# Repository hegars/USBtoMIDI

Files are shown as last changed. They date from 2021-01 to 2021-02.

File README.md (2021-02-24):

# USBtoMIDI

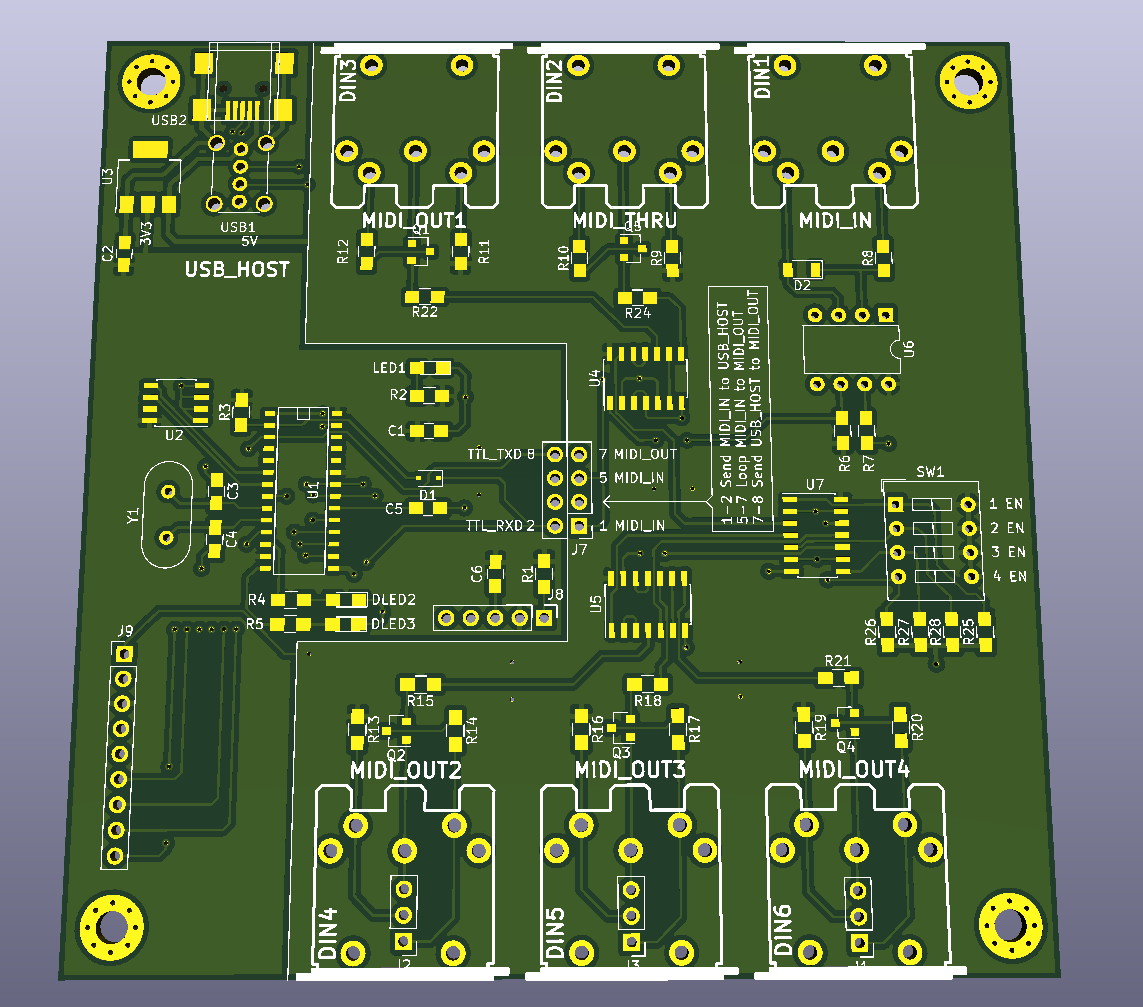
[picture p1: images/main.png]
usbtomidi


KiCAD design for Isolated 1 IN, 1 THRU and 4 OUT (with disable) MIDI distributor with USB Host Midi controller based on Microchip 24FJ64GB002 microcontroller with code from (https://www.hobbytronics.co.uk/audio-midi/usb-host-midi) on a 100mm x 100mm board for low cost production

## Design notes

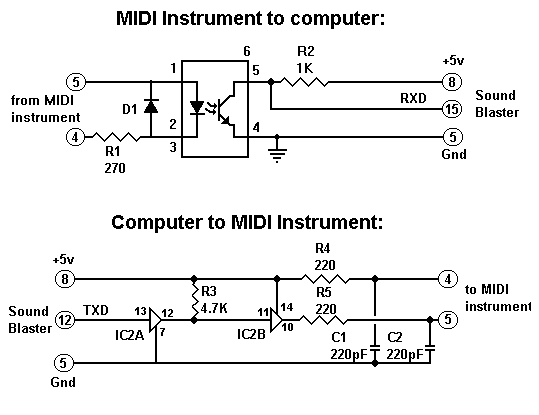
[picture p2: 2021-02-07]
images/sbmidi1.gif

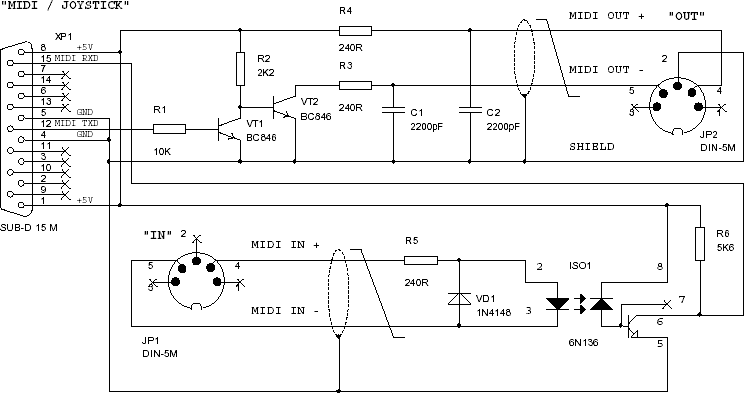
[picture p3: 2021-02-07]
images/image_pc2midicable.png

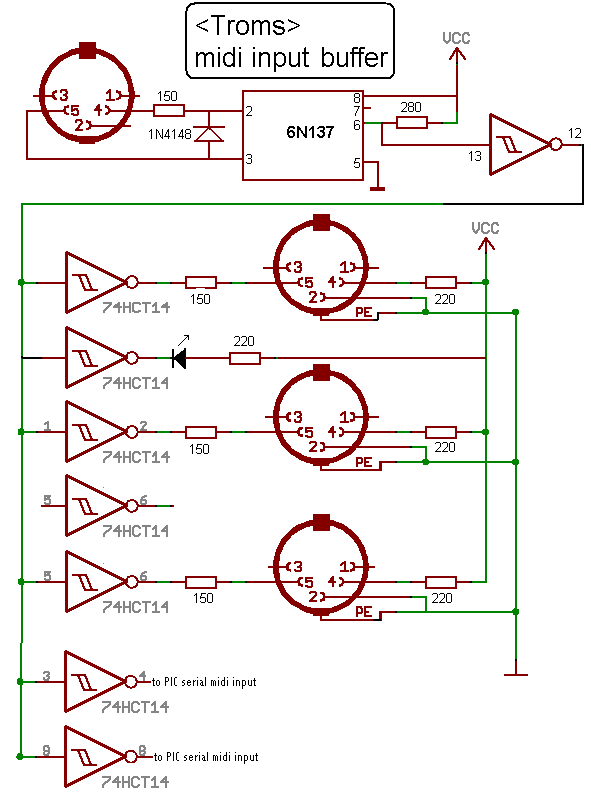
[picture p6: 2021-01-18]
images/SCH_Midibuffer.gif

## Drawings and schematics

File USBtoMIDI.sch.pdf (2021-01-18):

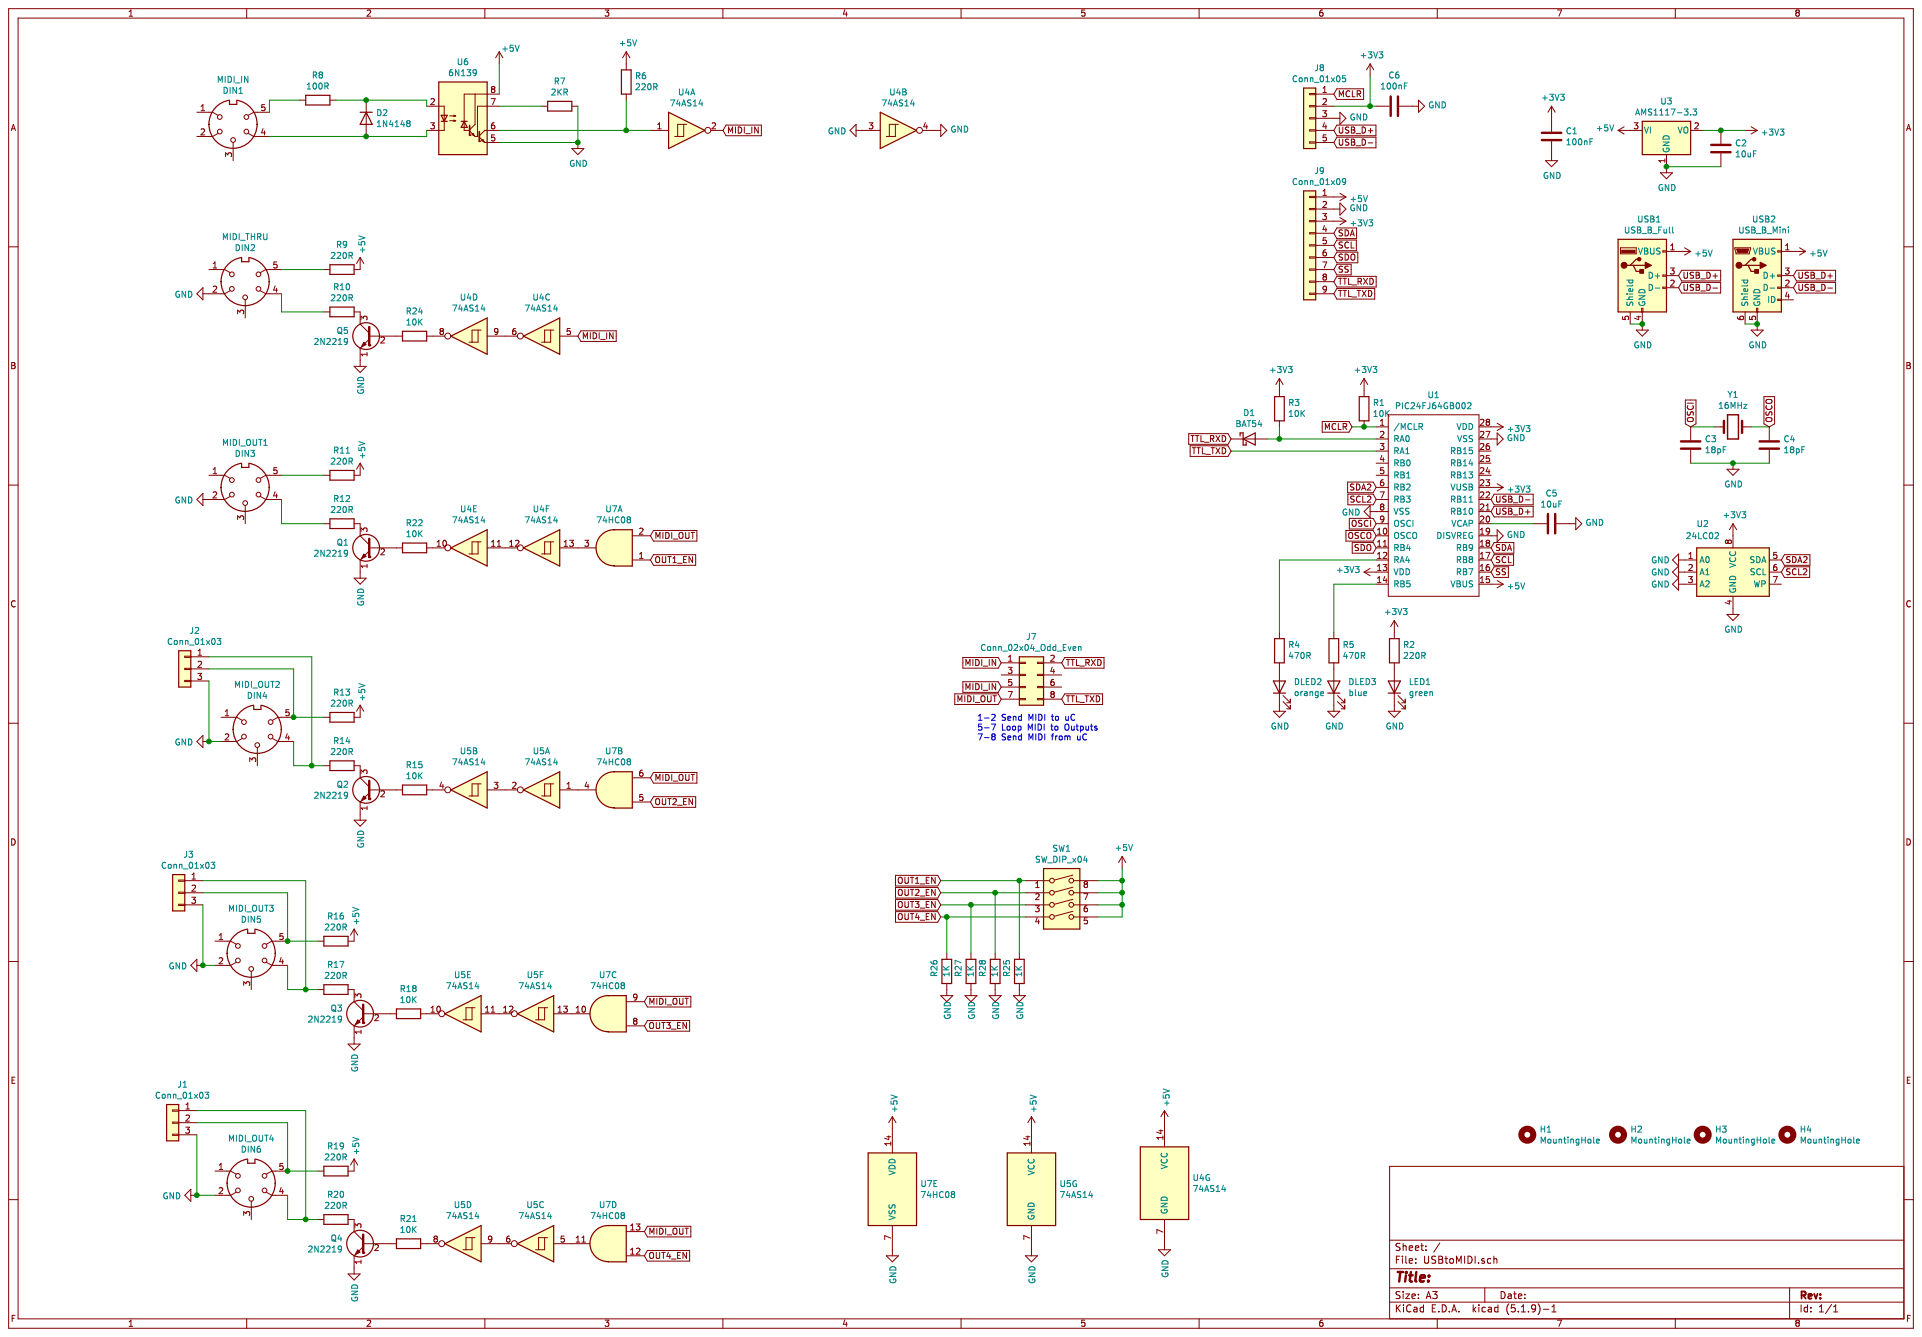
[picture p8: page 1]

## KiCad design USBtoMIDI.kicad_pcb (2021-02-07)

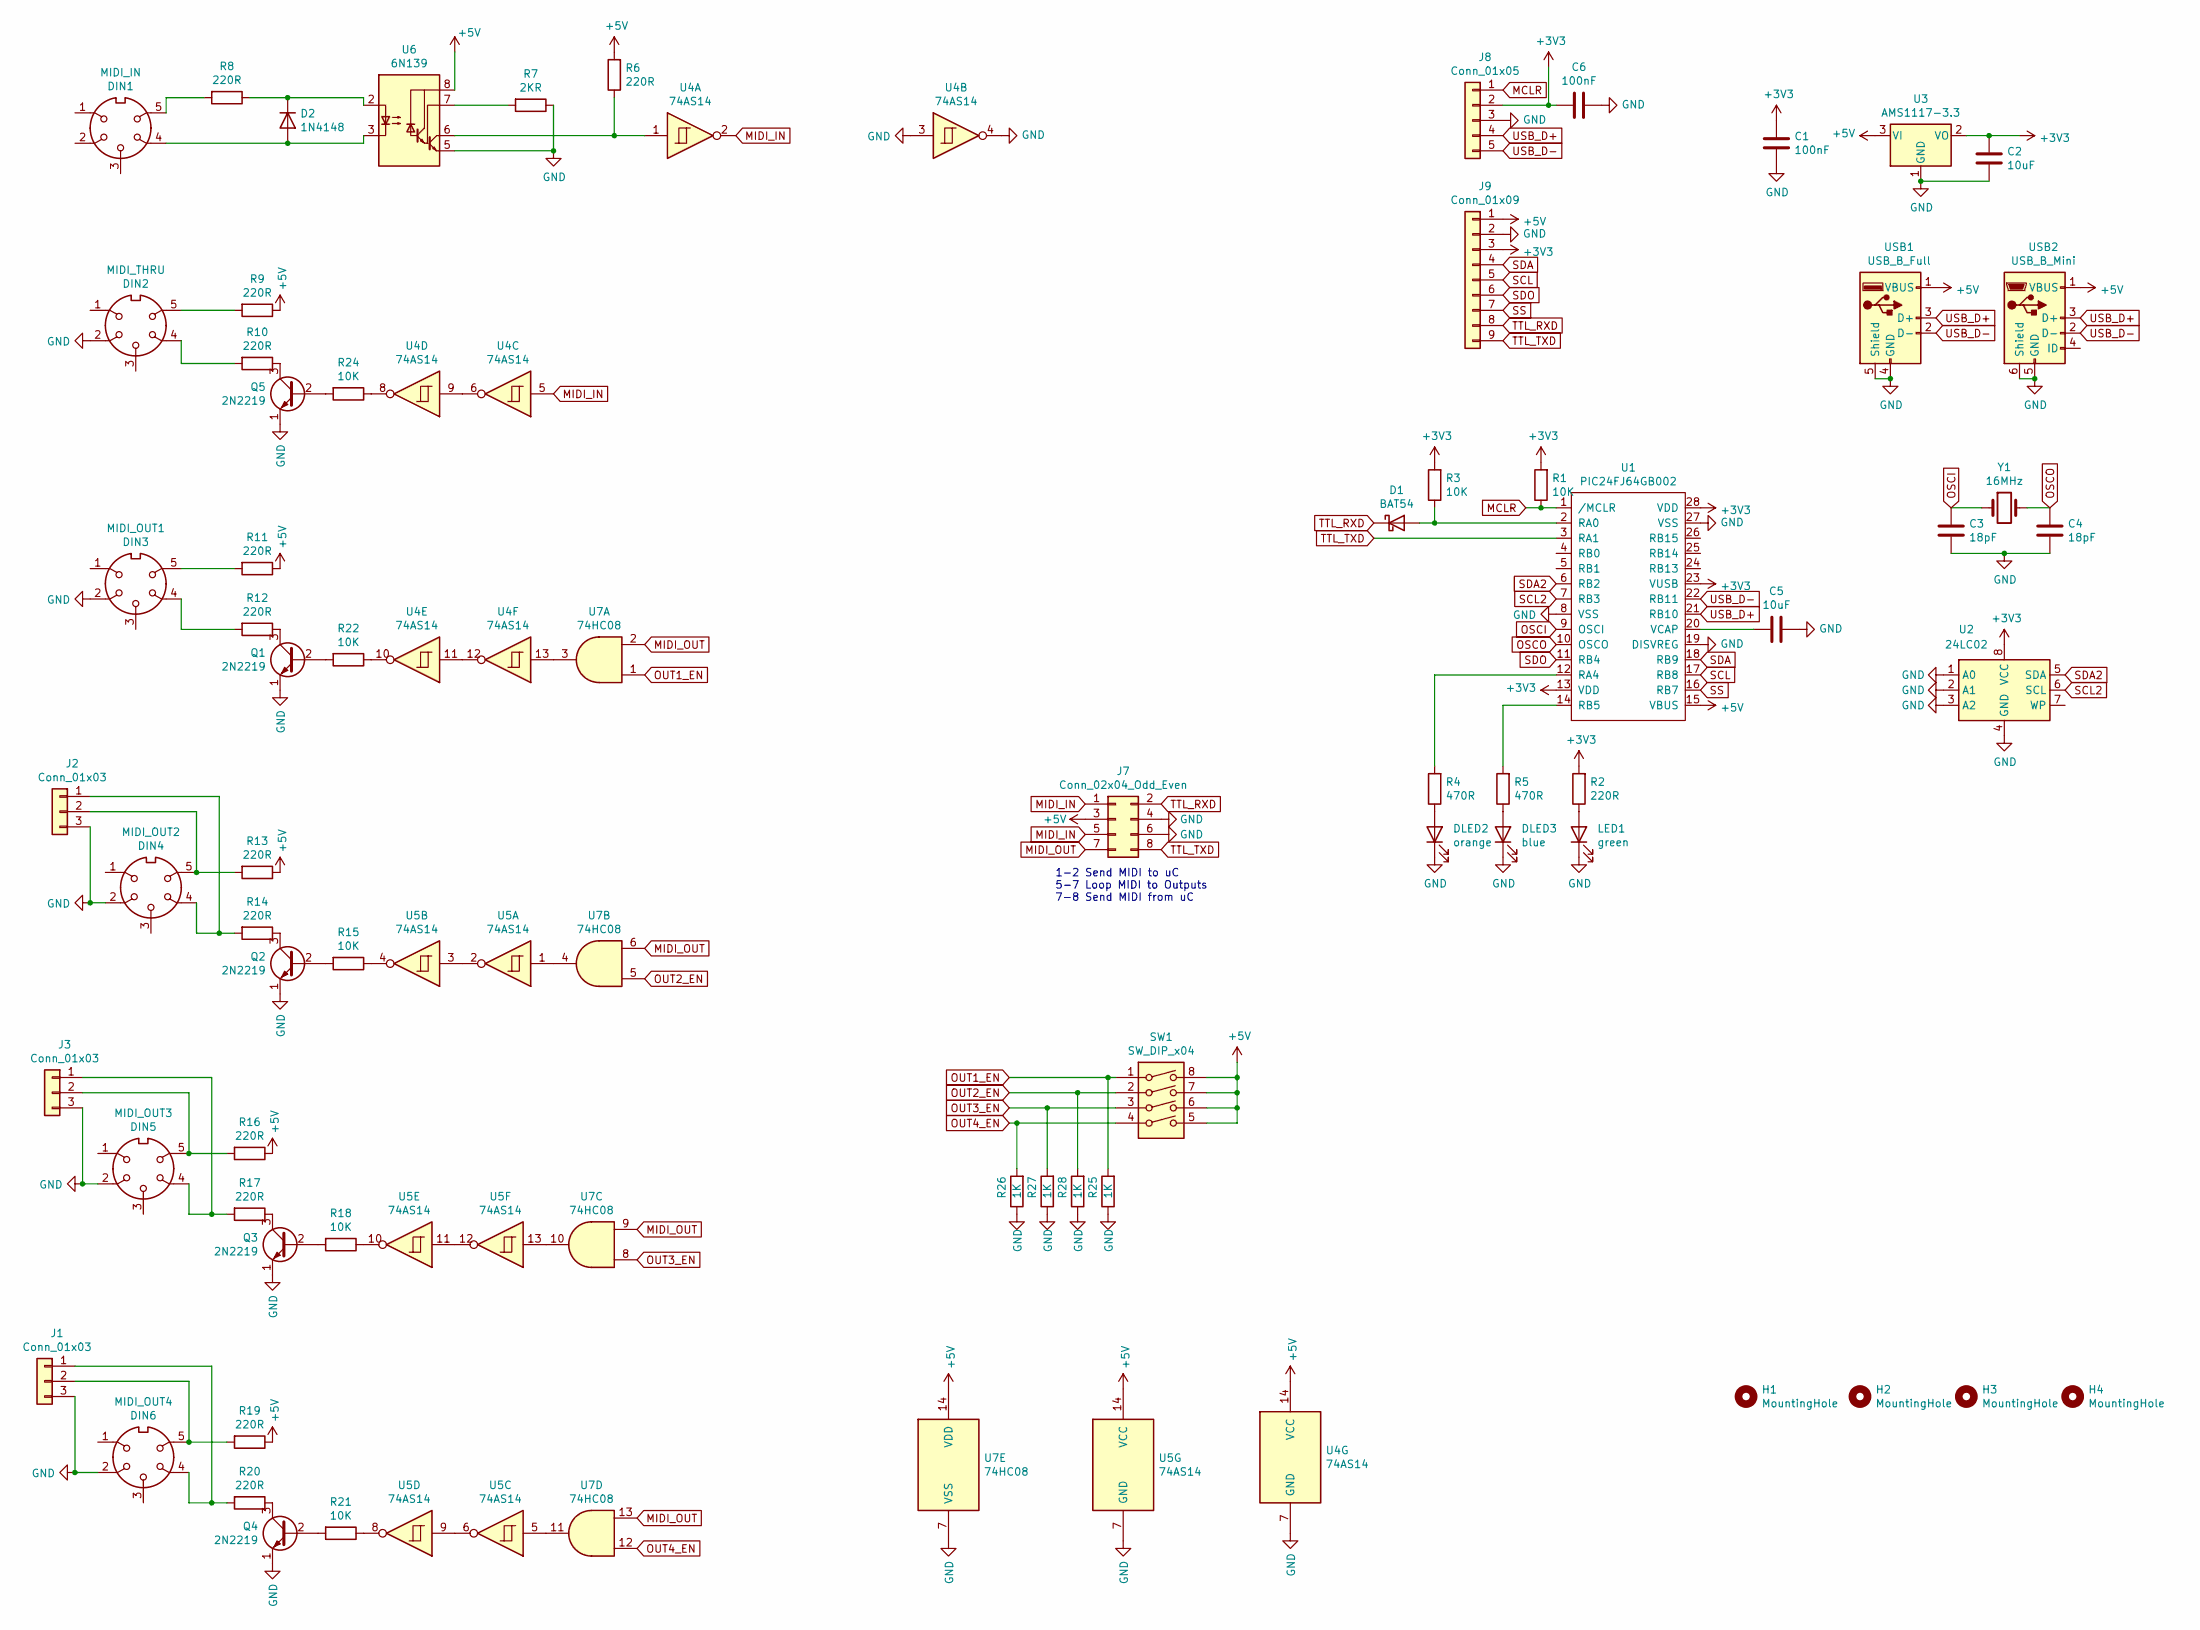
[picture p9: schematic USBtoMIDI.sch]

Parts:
C1, C6: 100nF; C_0805_HandSoldering
C2, C5: 10uF; C_0805_HandSoldering
C3, C4: 18pF; C_0805_HandSoldering
D1: BAT54; D_SOD-323
D2: 1N4148; D_1206
DIN1: MIDI_IN; din-5
DIN2: MIDI_THRU; din-5
DIN3: MIDI_OUT1; din-5
DIN4: MIDI_OUT2; din-5
DIN5: MIDI_OUT3; din-5
DIN6: MIDI_OUT4; din-5
DLED2: orange; LED_0805_HandSoldering
DLED3: blue; LED_0805_HandSoldering
H1, H2, H3, H4: MountingHole; MountingHole_3.2mm_M3_Pad_Via
J1, J2, J3: Conn_01x03; Pin_Header_Straight_1x03_Pitch2.54mm
J7: Conn_02x04_Odd_Even; Pin_Header_Straight_2x04_Pitch2.54mm
J8: Conn_01x05; Pin_Header_Straight_1x05_Pitch2.54mm
J9: Conn_01x09; Pin_Header_Straight_1x09_Pitch2.54mm
LED1: green; LED_0805_HandSoldering
Q1, Q2, Q3, Q4, Q5: 2N2219; SOT-23
R1, R3, R15, R18, R21, R22, R24: 10K; R_0805_HandSoldering
R2, R6, R8, R9, R10, R11, R12, R13, R14, R16, R17, R19, R20: 220R; R_0805_HandSoldering
R4, R5: 470R; R_0805_HandSoldering
R7: 2KR; R_0805_HandSoldering
R25, R26, R27, R28: 1K; R_0805_HandSoldering
SW1: SW_DIP_x04; SW_DIP_x4_W7.62mm_Slide
U1: PIC24FJ64GB002; SOIC-28
U2: 24LC02; SOIC-8_3.9x4.9mm_Pitch1.27mm
U3: AMS1117-3.3; SOT-223
U4, U5: 74AS14; SOIC-14_3.9x8.7mm_Pitch1.27mm
U6: 6N139; DIP-8_W7.62mm
U7: 74HC08; SOIC-14_3.9x8.7mm_Pitch1.27mm
USB1: USB_B_Full; USB_A_Vertical
USB2: USB_B_Mini; USB_Mini-B
Y1: 16MHz; Crystal_HC18-U_Vertical

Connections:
+3V3: C1.1, C2.1, C6.1, J8.2, J9.3, R1.2, R2.2, R3.2, U1.13 (VDD), U1.23 (VUSB), U1.28 (VDD), U2.8 (VCC), U3.2 (VO)
+5V: J7.3, J9.1, R6.2, R9.1, R11.1, R13.1, R16.1, R19.1, SW1.5, SW1.6, SW1.7, SW1.8, U1.15 (VBUS), U3.3 (VI), U4.14 (VCC), U5.14 (VCC), U6.8 (VCC), U7.14 (VDD), USB1.1 (VBUS), USB2.1 (VBUS)
GND: C1.2, C2.2, C3.1, C4.1, C5.1, C6.2, DIN2.2, DIN3.2, DIN4.2, DIN5.2, DIN6.2, DLED2.1 (K), DLED3.1 (K), J1.3, J2.3, J3.3, J7.4, J7.6, J8.3, J9.2, LED1.1 (K), Q1.1 (E), Q2.1 (E), Q3.1 (E), Q4.1 (E), Q5.1 (E), R7.1, R25.1, R26.1, R27.1, R28.1, U1.8 (VSS), U1.19 (DISVREG), U1.27 (VSS), U2.1 (A0), U2.2 (A1), U2.3 (A2), U2.4 (GND), U3.1 (GND), U4.3, U4.4, U4.7 (GND), U5.7 (GND), U6.5 (GND), U7.7 (VSS), USB1.4 (GND), USB1.5 (Shield), USB2.5 (GND), USB2.6 (Shield)
MCLR: J8.1, R1.1, U1.1 (/MCLR)
MIDI_IN: J7.1, J7.5, U4.2, U4.5
MIDI_OUT: J7.7, U7.2, U7.6, U7.9, U7.13
unnamed: C5.2, U1.20 (VCAP)
unnamed: D1.2 (A), R3.1, U1.2 (RA0)
unnamed: D2.1 (K), R8.1, U6.2 (C1)
unnamed: D2.2 (A), DIN1.4, U6.3 (C2)
unnamed: DIN1.5, R8.2
unnamed: DIN2.4, R10.2
unnamed: DIN2.5, R9.2
unnamed: DIN3.4, R12.2
unnamed: DIN3.5, R11.2
unnamed: DIN4.4, J2.1, R14.2
unnamed: DIN4.5, J2.2, R13.2
unnamed: DIN5.4, J3.1, R17.2
unnamed: DIN5.5, J3.2, R16.2
unnamed: DIN6.4, J1.1, R20.2
unnamed: DIN6.5, J1.2, R19.2
unnamed: DLED2.2 (A), R4.1
unnamed: DLED3.2 (A), R5.1
unnamed: LED1.2 (A), R2.1
unnamed: Q1.2 (B), R22.2
unnamed: Q1.3 (C), R12.1
unnamed: Q2.2 (B), R15.2
unnamed: Q2.3 (C), R14.1
unnamed: Q3.2 (B), R18.2
unnamed: Q3.3 (C), R17.1
unnamed: Q4.2 (B), R21.2
unnamed: Q4.3 (C), R20.1
unnamed: Q5.2 (B), R24.2
unnamed: Q5.3 (C), R10.1
unnamed: R4.2, U1.12 (RA4)
unnamed: R5.2, U1.14 (RB5)
unnamed: R6.1, U4.1, U6.6 (VO2)
unnamed: R7.2, U6.7 (VO1)
unnamed: R15.1, U5.4
unnamed: R18.1, U5.10
unnamed: R21.1, U5.8
unnamed: R22.1, U4.10
unnamed: R24.1, U4.8
unnamed: U4.6, U4.9
unnamed: U4.11, U4.12
unnamed: U4.13, U7.3
unnamed: U5.1, U7.4
unnamed: U5.2, U5.3
unnamed: U5.5, U7.11
unnamed: U5.6, U5.9
unnamed: U5.11, U5.12
unnamed: U5.13, U7.10
OSCI: C3.2, U1.9 (OSCI), Y1.1
OSCO: C4.2, U1.10 (OSCO), Y1.2
OUT1_EN: R25.2, SW1.1, U7.1
OUT2_EN: R28.2, SW1.2, U7.5
OUT3_EN: R27.2, SW1.3, U7.8
OUT4_EN: R26.2, SW1.4, U7.12
SCL: J9.5, U1.17 (RB8)
SCL2: U1.7 (RB3), U2.6 (SCL)
SDA: J9.4, U1.18 (RB9)
SDA2: U1.6 (RB2), U2.5 (SDA)
SDO: J9.6, U1.11 (RB4)
SS: J9.7, U1.16 (RB7)
TTL_RXD: D1.1 (K), J7.2, J9.8
TTL_TXD: J7.8, J9.9, U1.3 (RA1)
USB_D+: J8.4, U1.21 (RB10), USB1.3 (D+), USB2.3 (D+)
USB_D-: J8.5, U1.22 (RB11), USB1.2 (D-), USB2.2 (D-)

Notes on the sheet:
1-2 Send MIDI to uC 5-7 Loop MIDI to Outputs 7-8 Send MIDI from uC

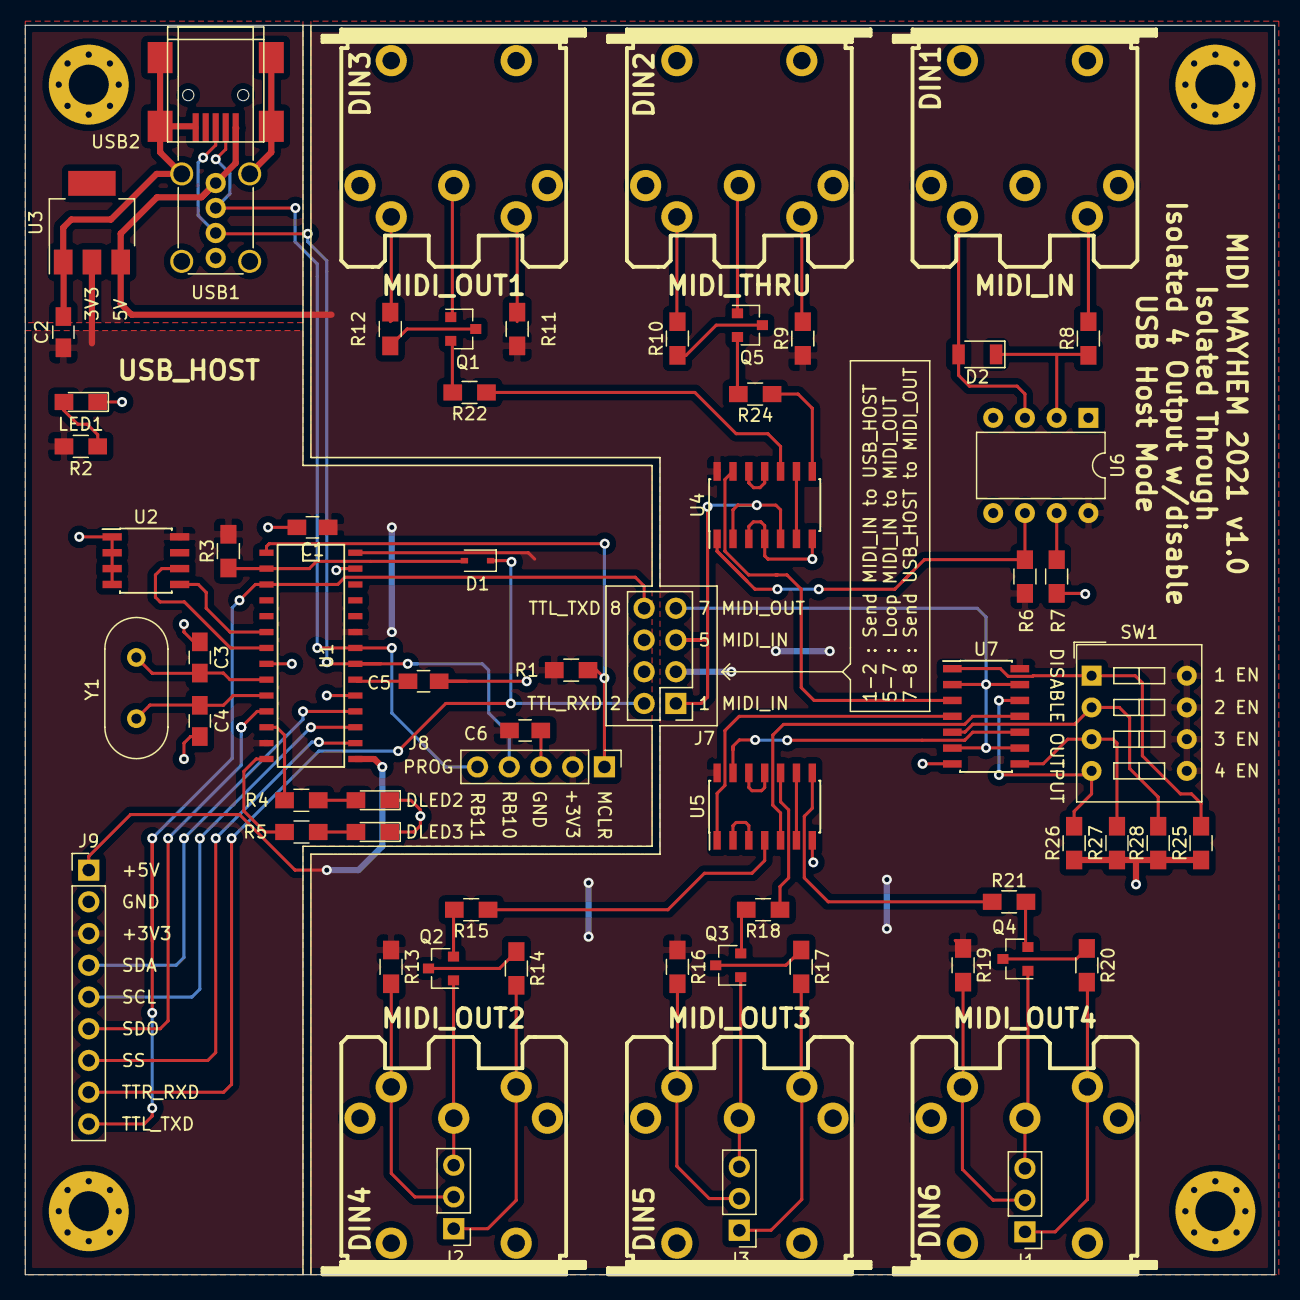
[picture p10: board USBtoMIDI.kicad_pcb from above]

Board: 2 copper layers, 100.0 x 100.0 mm, 70 parts (0 on the bottom side), 68 nets.

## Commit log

2021-01-18 changed usb type
    [USBtoMIDI.kicad_pcb, USBtoMIDI.sch]
2021-01-18 update config ports
    [USBtoMIDI.kicad_pcb, USBtoMIDI.sch]
2021-01-18 update logic
    [USBtoMIDI.kicad_pcb, USBtoMIDI.sch]
2021-01-18 silk updates
    [USBtoMIDI.kicad_pcb]
